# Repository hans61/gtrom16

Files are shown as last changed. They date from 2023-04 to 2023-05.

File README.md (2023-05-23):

"# gtrom16" 

Switcher for 16 Gigatron ROM versions

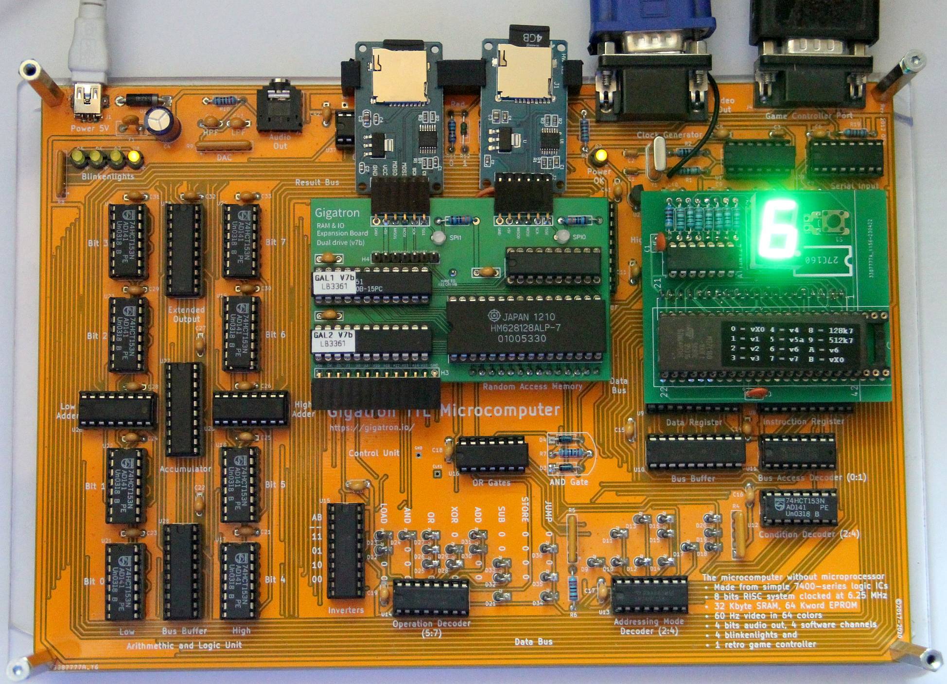
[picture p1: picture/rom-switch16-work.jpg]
switcher run


The switch stores the last selected ROM in the EEPROM of the ATtiny24. This allows a reset by switching the Gigatron off/on. I have found only 10 different ROMs so far (v1, v2, v3, v4, v5a, v6, vX0, v7, 128k7, (512k7)).
When storing in EEPROM, I rotate the cells so that 6,300,000 ROM changes should be possible.

schematic

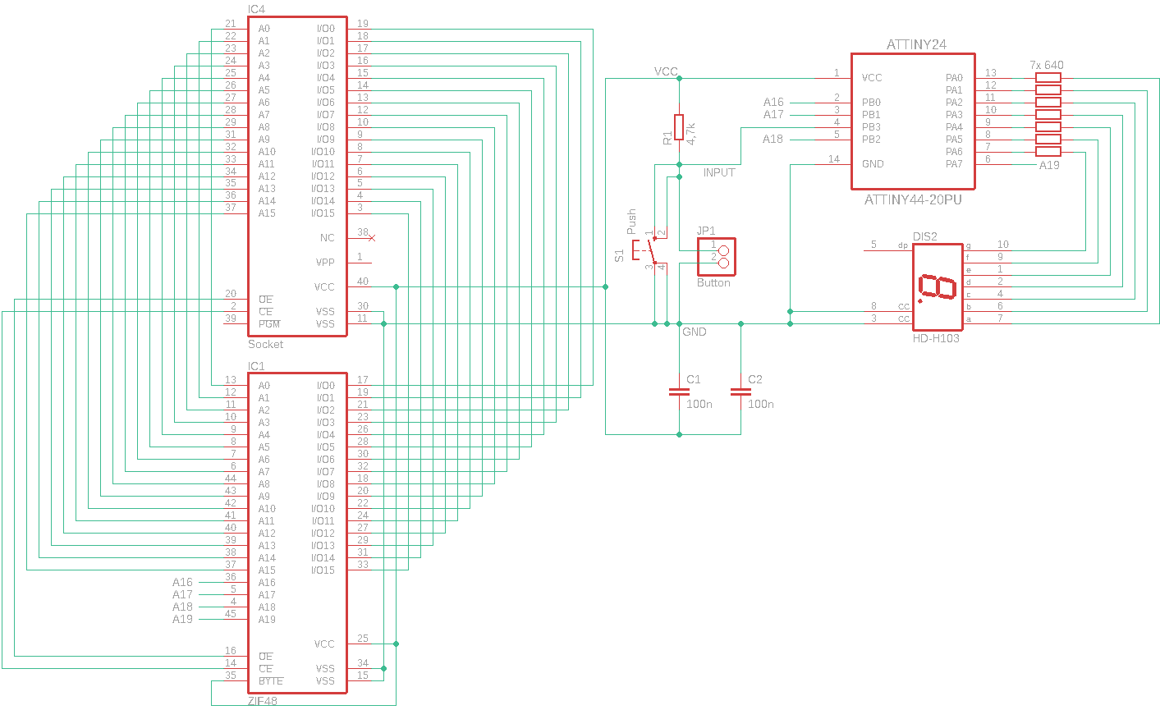
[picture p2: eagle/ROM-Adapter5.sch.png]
schematic


PCB

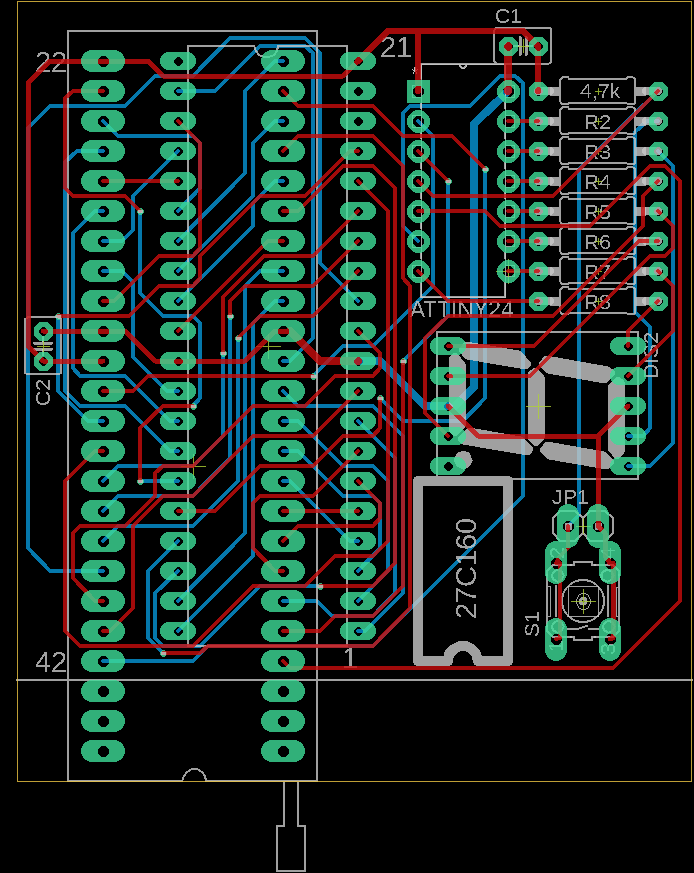
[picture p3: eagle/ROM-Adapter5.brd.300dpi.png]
pcb


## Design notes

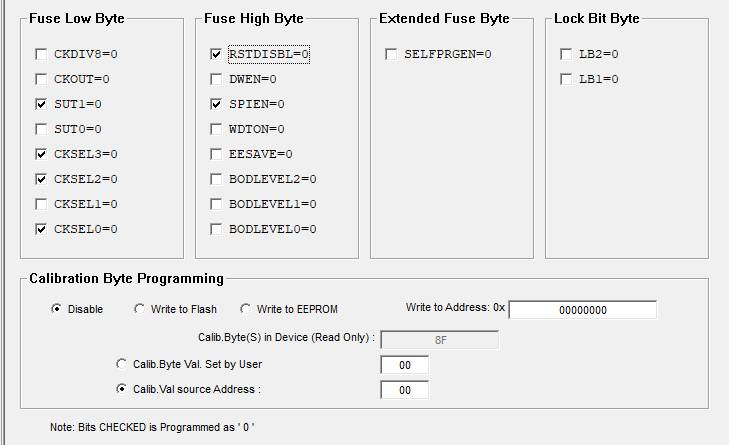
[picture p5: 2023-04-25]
ROM_Switcher/fuse-no-reset.jpg

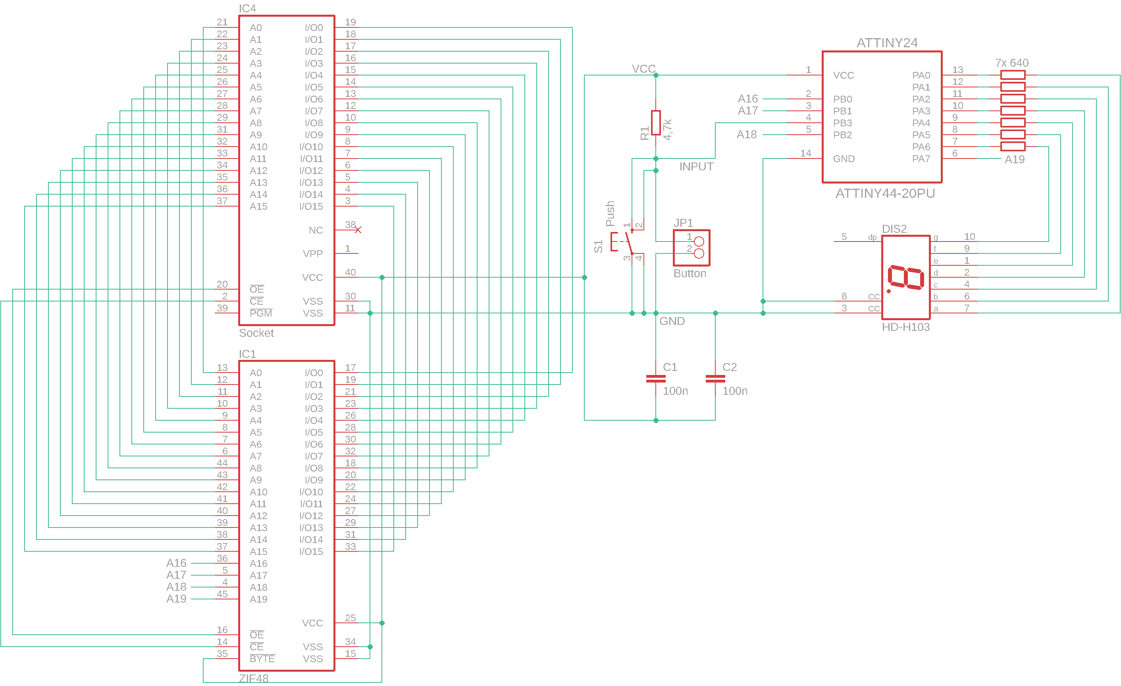
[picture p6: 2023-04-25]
eagle/ROM-Adapter5.sch.300dpi.png

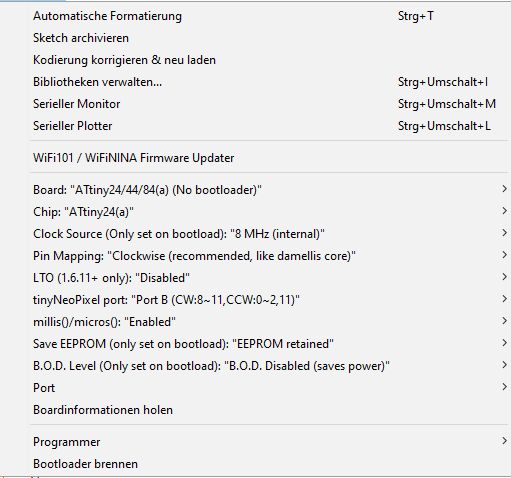
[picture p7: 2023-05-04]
ROM_Switcher/ide.jpg

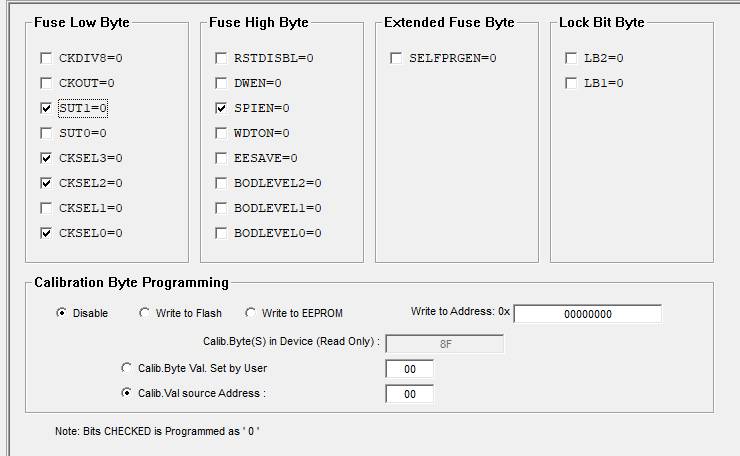
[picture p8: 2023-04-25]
ROM_Switcher/fuse.jpg

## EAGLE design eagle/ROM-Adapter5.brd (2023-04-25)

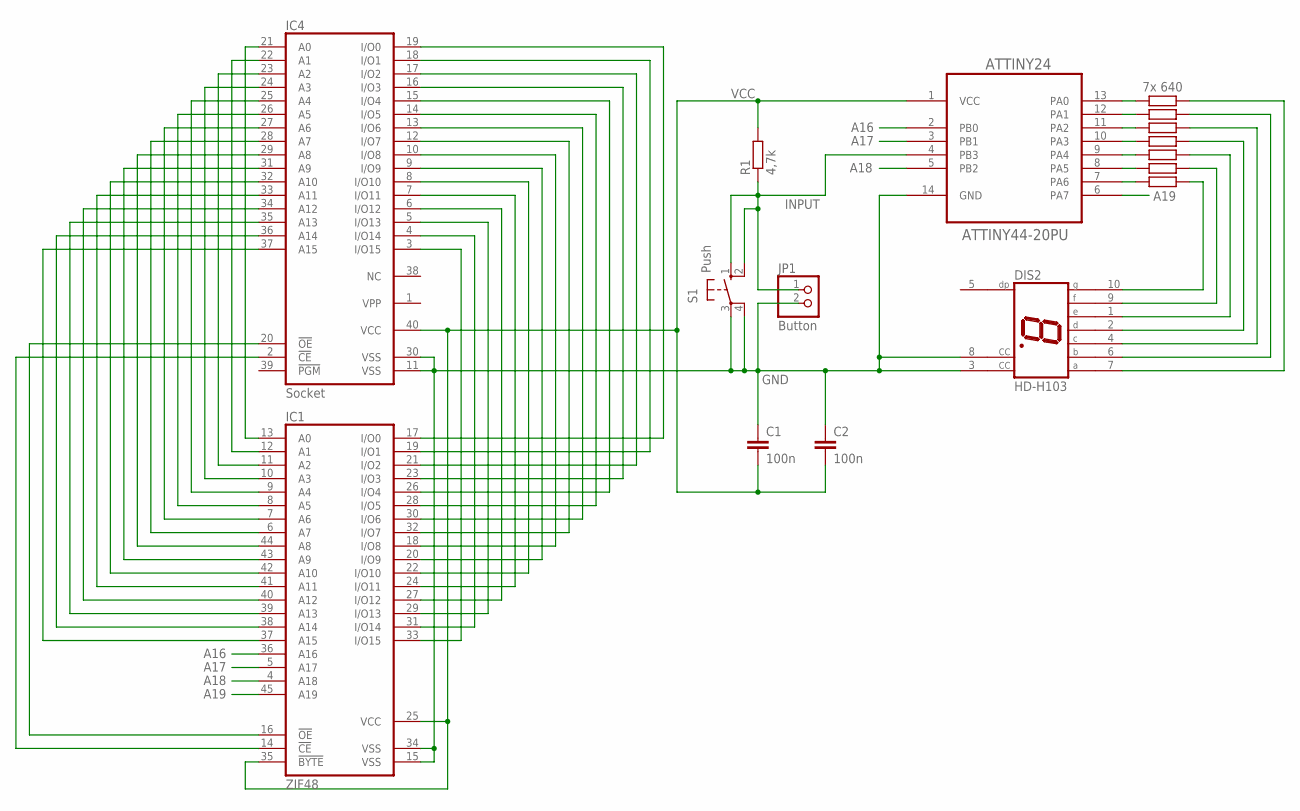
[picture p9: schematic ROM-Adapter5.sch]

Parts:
ATTINY24: ATTINY44-20PU; DIP254P762X533-14
C1, C2: 100n; C025-030X050
DIS2: HD-H103; HDSP-M
IC1: ZIF48; MEMORY-HITACHI_ZIF48
IC4: Socket; DIL40
JP1: Button; 1X02
R1: 4,7k; 0207/10
R2: 7x 640; 0207/10
R3, R4, R5, R6, R7, R8: 640; 0207/10
S1: Push; B3F-10XX

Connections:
A16: ATTINY24.2 (PB0), IC1.36 (A16)
A17: ATTINY24.3 (PB1), IC1.5 (A17)
A18: ATTINY24.5 (PB2), IC1.4 (A18)
A19: ATTINY24.6 (PA7), IC1.45 (A19)
GND: ATTINY24.14 (GND), C1.1, C2.1, DIS2.3 (CC), DIS2.8 (CC), IC1.15 (VSS), IC1.34 (VSS), IC4.11 (VSS), IC4.30 (VSS), JP1.2, S1.3, S1.4 (P1)
INPUT: ATTINY24.4 (PB3), JP1.1, R1.1, S1.1 (S), S1.2 (S1)
unnamed: IC1.13 (A0), IC4.21 (A0)
unnamed: IC1.12 (A1), IC4.22 (A1)
unnamed: ATTINY24.13 (PA0), R2.1
unnamed: IC1.11 (A2), IC4.23 (A2)
unnamed: IC1.10 (A3), IC4.24 (A3)
unnamed: IC1.9 (A4), IC4.25 (A4)
unnamed: IC1.8 (A5), IC4.26 (A5)
unnamed: IC1.7 (A6), IC4.27 (A6)
unnamed: IC1.6 (A7), IC4.28 (A7)
unnamed: IC1.44 (A8), IC4.29 (A8)
unnamed: IC1.43 (A9), IC4.31 (A9)
unnamed: IC1.42 (A10), IC4.32 (A10)
unnamed: IC1.41 (A11), IC4.33 (A11)
unnamed: IC1.40 (A12), IC4.34 (A12)
unnamed: IC1.39 (A13), IC4.35 (A13)
unnamed: IC1.38 (A14), IC4.36 (A14)
unnamed: IC1.37 (A15), IC4.37 (A15)
unnamed: IC1.16 (!OE), IC4.20 (!OE)
unnamed: IC1.14 (!CE), IC4.2 (!CE)
unnamed: DIS2.10 (G), R8.2
unnamed: IC1.33 (I/O15), IC4.3 (I/O15)
unnamed: DIS2.9 (F), R7.2
unnamed: IC1.31 (I/O14), IC4.4 (I/O14)
unnamed: IC1.29 (I/O13), IC4.5 (I/O13)
unnamed: IC1.27 (I/O12), IC4.6 (I/O12)
unnamed: IC1.24 (I/O11), IC4.7 (I/O11)
unnamed: IC1.22 (I/O10), IC4.8 (I/O10)
unnamed: IC1.20 (I/O9), IC4.9 (I/O9)
unnamed: IC1.18 (I/O8), IC4.10 (I/O8)
unnamed: IC1.32 (I/O7), IC4.12 (I/O7)
unnamed: IC1.30 (I/O6), IC4.13 (I/O6)
unnamed: IC1.28 (I/O5), IC4.14 (I/O5)
unnamed: IC1.26 (I/O4), IC4.15 (I/O4)
unnamed: IC1.23 (I/O3), IC4.16 (I/O3)
unnamed: IC1.21 (I/O2), IC4.17 (I/O2)
unnamed: IC1.19 (I/O1), IC4.18 (I/O1)
unnamed: IC1.17 (I/O0), IC4.19 (I/O0)
unnamed: ATTINY24.12 (PA1), R3.1
unnamed: ATTINY24.11 (PA2), R4.1
unnamed: ATTINY24.10 (PA3), R5.1
unnamed: ATTINY24.9 (PA4), R6.1
unnamed: ATTINY24.8 (PA5), R7.1
unnamed: ATTINY24.7 (PA6), R8.1
unnamed: DIS2.1 (E), R6.2
unnamed: DIS2.2 (D), R5.2
unnamed: DIS2.4 (C), R4.2
unnamed: DIS2.6 (B), R3.2
unnamed: DIS2.7 (A), R2.2
VCC: ATTINY24.1 (VCC), C1.2, C2.2, IC1.25 (VCC), IC1.35 (!BYTE), IC4.40 (VCC), R1.2

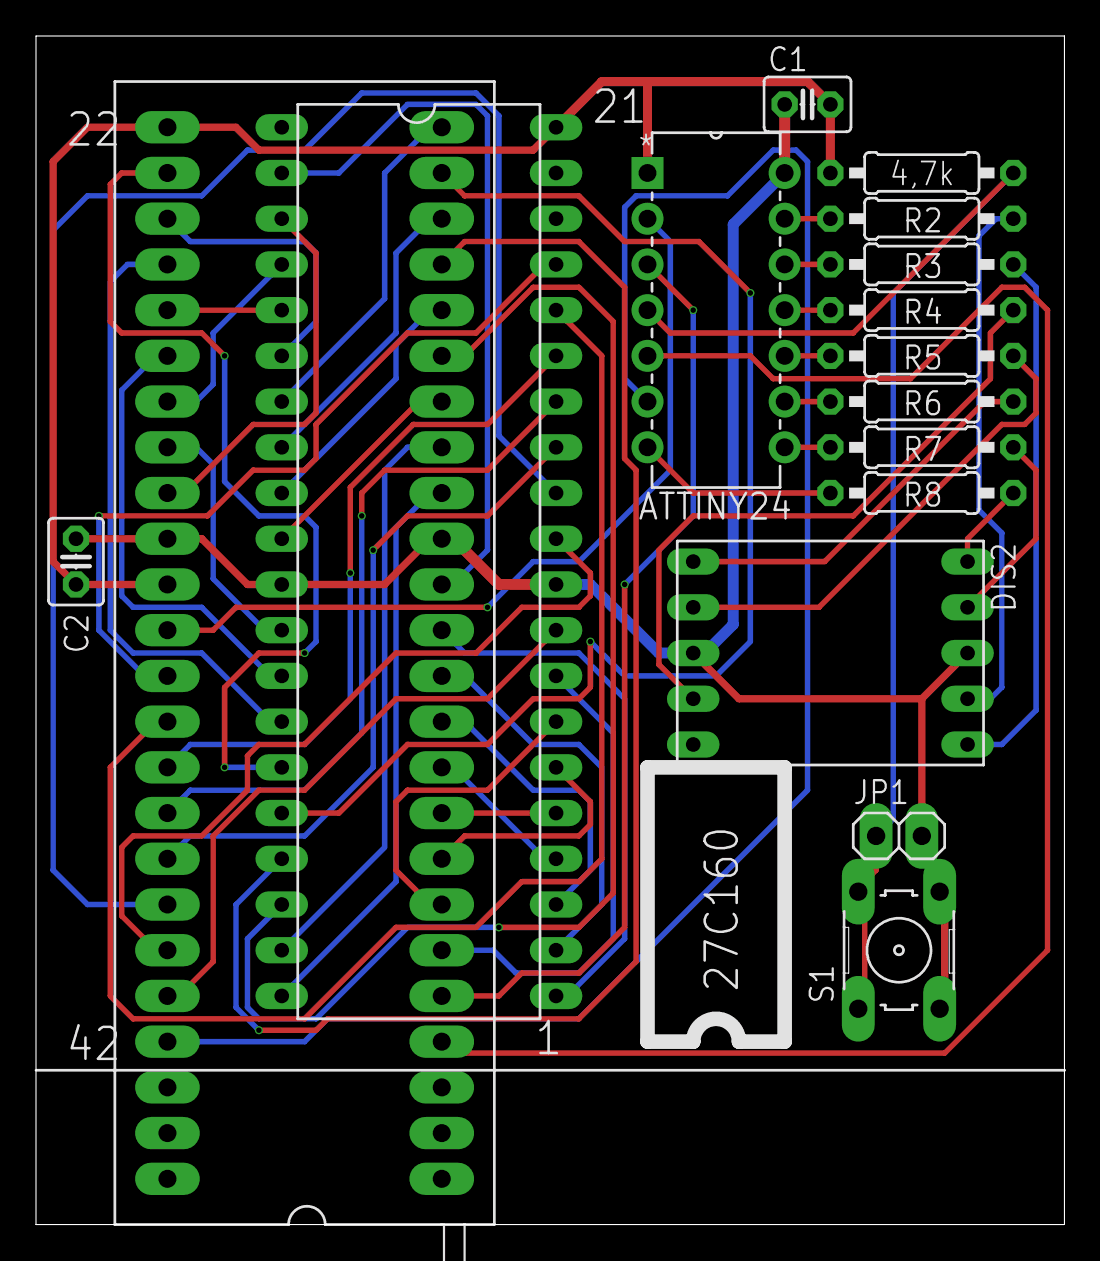
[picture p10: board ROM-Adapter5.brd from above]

Board: 2 copper layers, 57.1 x 66.0 mm, 16 parts (0 on the bottom side), 55 nets.

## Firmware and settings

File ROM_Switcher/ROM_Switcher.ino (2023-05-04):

/*
  First test for ROM switch
  8 MHz internal, Pin Mapping: Clockwise, LTO: disable, tinyNeoPixel poer: Port B millis(): enable
*/

#include <EEPROM.h>

//#define debug

#define button 11;
#define A16 0;	// B0
#define A17 1;	// B1
#define A18 2;	// B2
#define A19 3;	// A7

#define ADDR 0

#define IF_KEY_PRESSED (PINB & (1 << 3)) == 0
#define ELAPSED_TIME (millis() - lastAction)
#define NOW millis()

#define TIME_DEBOUNCE 50
#define TIME_LONG_PRESSED 1000
#define TIME_LONG_RELEASED 2000
#define TIME_VERY_LONG_PRESSED 3000

#define STATE_LONG_RELEASED 1
#define STATE_NO_KEY_PRESSED 2
#define STATE_PRESSED 3
#define STATE_LONG_PRESSED 4
#define STATE_VERY_LONG_PRESSED 5
#define STATE_NOW_PRESSED 6

// Character for seven segment display
byte display[] = {
  0b00111111, // 0
  0b00000110, // 1
  0b01011011, // 2
  0b01001111, // 3
  0b01100110, // 4
  0b01101101, // 5
  0b01111101, // 6
  0b00000111, // 7
  0b01111111, // 8
  0b01101111, // 9
  0b01110111, // A
  0b01111100, // b
  0b01011000, // c
  0b01011110, // d
  0b01111001, // E
  0b01110001, // F
  0b01011100, // o
  0b01001000, // =
  0b01001001, // =-
  0b00000000  // blank
};

#define BLANK 19

byte tmp;
byte romIdx;                                  // ROM Index (selected ROM)
byte romLastIdx = 17;
byte eepromAddr;                              // ROM Index (selected ROM)
long buttonPressedTime = 0;                   // Keystroke duration
long lastAction = NOW;                        // Start button pressed
byte lastButtonState = STATE_NO_KEY_PRESSED;  // Status of the last keystroke
byte saveEeprom = 1;

// Key query
byte getButton() {
  if (ELAPSED_TIME > TIME_DEBOUNCE ) {

    if (IF_KEY_PRESSED) {                                                                           // Key pressed
      //if ((lastButtonState == STATE_NO_KEY_PRESSED) || (lastButtonState == TIME_LONG_RELEASED)) { // not pressed before
      if (lastButtonState < STATE_PRESSED) {                                                        // not pressed before
        lastButtonState = STATE_NOW_PRESSED;
        lastAction = NOW;
      } else {                                                                                      // Key is still pressed
        if (ELAPSED_TIME > TIME_VERY_LONG_PRESSED) lastButtonState = STATE_VERY_LONG_PRESSED;
      }
    } else {                                                                                        // Key not pressed
      //if ((lastButtonState != STATE_NO_KEY_PRESSED) && (lastButtonState != TIME_LONG_RELEASED)) { // Key was pressed [Taste war gedrückt, wurde eben losgelassen]
      if (lastButtonState >= STATE_PRESSED) {                                                       // Key was pressed
        lastButtonState = STATE_NO_KEY_PRESSED;
        buttonPressedTime = ELAPSED_TIME;
        lastAction = NOW;
        if (buttonPressedTime > TIME_VERY_LONG_PRESSED) {
          return STATE_VERY_LONG_PRESSED;
        } else if (buttonPressedTime > TIME_LONG_PRESSED) {
          return STATE_LONG_PRESSED;
        } else {
          return STATE_PRESSED;
        }
      } else {                                                                                       // Key is not pressed and was not pressed
        if (ELAPSED_TIME > TIME_LONG_RELEASED) lastButtonState = STATE_LONG_RELEASED;
      }
    }
    return lastButtonState;

  } else {                                                                                           // in debounce time
    return STATE_NO_KEY_PRESSED;
  }
}

// print char
void setDisplay(byte id) {
  if (id < 20) PORTA = (PORTA & 0x80) | display[id];
}

// Select ROM bank, activate
void setAddress(byte id) {
  PORTB = (PORTB & 0b11111000) | (id & 0b00000111);
  if ((id & 0b00001000) == 0) {
    PORTA = PORTA & 0b01111111;
  } else {
    PORTA = (PORTA & 0b01111111) | 0b10000000;
  }
}


void writeEEPROM() {
  if (eepromAddr < 2 || eepromAddr > 126) { // Address must be even and between 2..126
    eepromAddr = 2;
    EEPROM.update(ADDR, eepromAddr);
  }
  tmp = EEPROM.read(eepromAddr + 1);        // Increase write counter for cell
  tmp--;
  EEPROM.write(eepromAddr + 1, tmp);
  if (tmp == 0) {                           // switch to the next cell on overflow
    eepromAddr += 2;
    if (eepromAddr > 126) eepromAddr = 2;
    EEPROM.update(ADDR, eepromAddr);        // Set pointer to current cell
  }
  //eepromAddr = 0;
  romIdx &= 0x0F;
  setDisplay(BLANK);
  delay(250);
#ifdef debug
  setDisplay(eepromAddr);
  delay(250);
#endif
  EEPROM.update(eepromAddr, romIdx);        // Save ROM index
  setDisplay(BLANK);
  delay(100);
  setDisplay(eepromAddr);
  delay(250);
  setDisplay(BLANK);
  delay(150);
}

void setup() {
  DDRA = 0xFF;
  DDRB = 0x07; 	                            // 0b00000111;
  eepromAddr = EEPROM.read(ADDR);
  if (eepromAddr > 0b01111110) {
    setAddress(0);
    eepromAddr = 2;
    EEPROM.write(ADDR, 2);

  } else {
    eepromAddr &= 0b01111110;
    romIdx = EEPROM.read(eepromAddr);       // read default index from eeprom
    romIdx &= 0x0F;
    setAddress(romIdx);
#ifdef debug
    setDisplay(BLANK);
    delay(250);
#endif
    setDisplay(eepromAddr >> 4);
    delay(250);
    setDisplay(eepromAddr & 0x0F);
    delay(250);
#ifdef debug
    setDisplay(BLANK);
    delay(250);
    setDisplay(romIdx);
    delay(250);
    setDisplay(BLANK);
    delay(250);
#endif
  }
}

void loop() {
  if (romIdx != romLastIdx) {
    setAddress(romIdx);          // activate selected bank
    setDisplay(romIdx & 0x0F);   // show selected bank
    romLastIdx = romIdx;
  }

  tmp = getButton();
  //setDisplay(tmp);
  if (tmp == STATE_LONG_RELEASED) {
    if (saveEeprom == 0) {
      saveEeprom = 1;
      writeEEPROM();
      setDisplay(romIdx & 0x0F);
    }
  } else if (tmp == STATE_PRESSED) {             // key pressed, switch to the next bank
    romIdx++;
    romIdx &= 0x0F;
    saveEeprom = 0;
  } else if (tmp == STATE_LONG_PRESSED) {        // key pressed for a long time, set bank to 0 (my ROM vX0)
    romIdx = 0;
    saveEeprom = 0;
  } else if (tmp == STATE_VERY_LONG_PRESSED) {   // key pressed very long, set bank to 8 (my ROM 128k7)
    romIdx = 8;
    saveEeprom = 0;
  }
}
